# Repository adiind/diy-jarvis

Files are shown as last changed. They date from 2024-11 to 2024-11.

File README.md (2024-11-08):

# Voice-Controlled Smart Home Assistant 🎙️🏠
 




An intelligent IoT device built using the Maixduino Kit for AI + IoT, integrating voice recognition and motion detection to interact with Home Assistant via MQTT. The assistant recognizes specific voice commands, detects motion, and provides visual feedback through four white LEDs and two vertical RGB LED light bars. It updates the state of various entities in Home Assistant, enabling automation and enhancing user interaction with the smart home environment.

<div align="center">
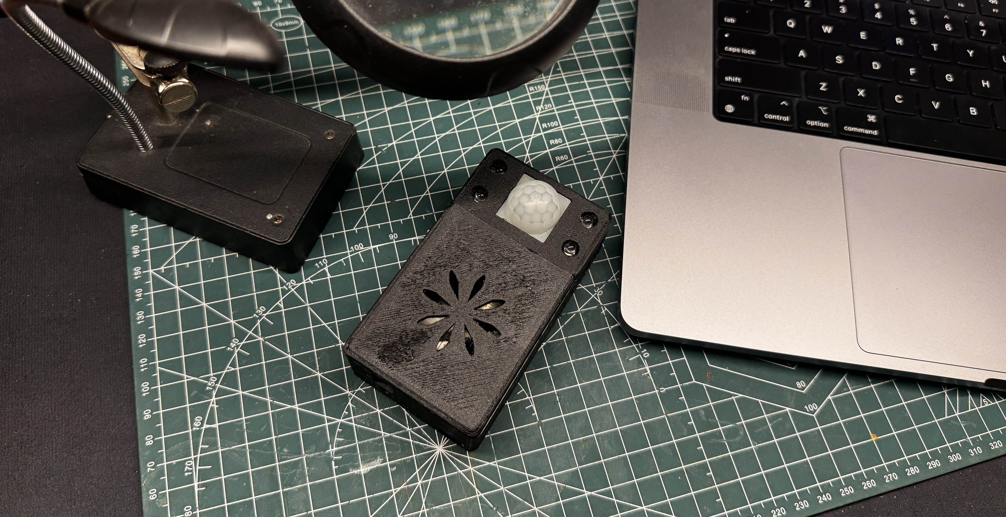
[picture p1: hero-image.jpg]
Smart Home Assistant Setup
  
</div>

## ✨ Key Features

- 🗣️ **Advanced Voice Recognition**: Custom-trained models with project-specific commands
- 📡 **Motion Detection**: PIR sensor technology for automated activation
- 💡 **Dynamic Visual Feedback**: 4 status LEDs + RGB light bars for clear system status
- 🏠 **Home Assistant Integration**: Comprehensive MQTT communication
- 🌙 **Smart Night Navigation**: Automatic lighting with motion detection
- ⚡ **Real-time State Management**: Instant updates and automation triggers
- 🛠️ **Easy Installation**: Non-destructive mounting and simple reset mechanism

## 📑 Table of Contents

- [Installation](#-installation)
- [Hardware Setup](#-hardware-setup)
- [Software Configuration](#-software-configuration)
- [Voice Model Generation](#-voice-model-generation)
- [Usage Guide](#-usage-guide)
- [Troubleshooting](#-troubleshooting)
- [Contributing](#-contributing)
- [License](#-license)

## 📦 Installation

### Hardware Requirements

Component | Purpose | Specifications
----------|----------|-------------
Maixduino Kit | Core Processing | AI + IoT version
ESP32 Module | Wi-Fi Communication | Built into Maixduino
PIR Sensor (HC-SR501) | Motion Detection | 3.3V compatible
Status LEDs | Visual Feedback | 4x white LEDs
Current Limiting Resistors | LED Protection | 4x 220Ω
RGB Light Bars | Dynamic Feedback | 2x 104 LED strips (1.5m)
ESP8266 | LED Control | WLED firmware
Power Supply | System Power | 12V DC barrel connector
Mounting Hardware | Installation | 3M Command Strips
Reset Wires | Easy Access | 2x insulated wires

### Hardware Assembly

1. **Power Connections**
   ```
   12V DC → Maixduino barrel jack
   GND → Common ground bus
   ```

2. **Sensor Wiring**
   ```
   PIR VCC → 3.3V
   PIR GND → GND
   PIR OUT → D8
   ```

3. **Status LEDs**
   ```
   System LED  → D5 + 220Ω → GND
   Speech LED  → D4 + 220Ω → GND
   Network LED → D3 + 220Ω → GND
   Motion LED  → D2 + 220Ω → GND
   ```

4. **Light Bars**
   - Mount vertically using Command Strips
   - Connect to ESP8266 running WLED
   - Power via 12V supply

5. **Reset Access**
   - Connect wire 1 to Reset pin
   - Connect wire 2 to GND pin
   - Route both wires through case opening
   - Insulate exposed ends
   - Label wires clearly

## 🎤 Voice Model Generation

### Prerequisites
- Maixduino Kit
- USB Cable
- CoolTerm Software
- Python 3.x Environment

### Voice Recording Environment Setup

1. **Physical Setup**
   - Install device in final location
   - Ensure case is fully assembled
   - Position at intended height
   - Verify proper ventilation

2. **Recording Environment**
   - Minimize background noise
   - Maintain consistent ~50cm distance
   - Use normal speaking voice
   - Test acoustics of space

### CoolTerm Configuration

1. **Initial Setup**
   ```
   Port: Select Maixduino COM port
   Baud Rate: 115200
   Data Bits: 8
   Stop Bits: 1
   Parity: None
   ```

2. **Buffer Settings**
   - Set buffer size to 75000
   - Enable "Capture to Text File"
   - Clear buffer between recordings

### Reset Procedure for Voice Model Recording

1. **Preparation**
   - Locate labeled reset and GND wires
   - Ensure clean wire ends
   - Have recording script ready

2. **Recording Process**
   - Touch reset and GND wires together briefly
   - Wait for LED confirmation of reboot
   - Begin recording when prompted
   - Maintain consistent voice level
   - Complete all 6 samples
   - Save file with descriptive name

3. **Safety Notes**
   - Keep wire ends separated when not in use
   - Consider adding small connectors
   - Avoid touching other components
   - Keep wires away from interference sources

### Project-Specific Voice Commands

Command ID | Phrase | Function | Description
-----------|--------|----------|-------------
1 | "Alfred Let's Go" | System Activation | Initializes main system functions
2 | "Bye Bye Jarvis" | System Shutdown | Graceful shutdown sequence
3 | "Cooking Mode" | Kitchen Control | Activates kitchen-specific settings
4 | "Goodnight Jarvis" | Night Mode | Evening shutdown routine
5 | "Jarvis Good Morning" | Morning Mode | Morning activation sequence
6 | "Jarvis Lights On" | Lighting Control | Activates configured lights
7 | "Lights Off Jarvis" | Lighting Control | Deactivates all lights
8 | "Wake Up Jarvis" | System Wake | Resumes from sleep mode
9 | "Clap Clap" | Attention Mode | Quick system attention
10 | "Jarvis Demo Mode" | Demonstration | Shows system capabilities

## 💻 Software Configuration

### MQTT Topics Structure
```cpp
// System State Topics
const char* motion_state_topic = "home-assistant/voice-control/motion/state";
const char* alfred_state_topic = "home-assistant/voice-control/alfred/state";
const char* system_state_topic = "home-assistant/voice-control/system/state";
const char* cooking_state_topic = "home-assistant/voice-control/cooking/state";
const char* goodnight_state_topic = "home-assistant/voice-control/goodnight/state";
const char* goodmorning_state_topic = "home-assistant/voice-control/goodmorning/state";
const char* light_state_topic = "home-assistant/voice-control/light/state";
```

### Home Assistant Configuration
```yaml
# MQTT Configuration
mqtt:
  binary_sensor:
    - name: "Voice Control Motion"
      state_topic: "home-assistant/voice-control/motion/state"
      device_class: "motion"
      unique_id: "voice-control-motion"

  switch:
    - name: "Alfred Mode"
      state_topic: "home-assistant/voice-control/alfred/state"
      unique_id: "voice-control-alfred"
      icon: "mdi:butler"
    
    - name: "Voice Control System"
      state_topic: "home-assistant/voice-control/system/state"
      unique_id: "voice-control-system"
      icon: "mdi:voice"
    
    - name: "Cooking Mode"
      state_topic: "home-assistant/voice-control/cooking/state"
      unique_id: "voice-control-cooking"
      icon: "mdi:stove"
    
    - name: "Goodnight Mode"
      state_topic: "home-assistant/voice-control/goodnight/state"
      unique_id: "voice-control-goodnight"
      icon: "mdi:weather-night"
    
    - name: "Good Morning Mode"
      state_topic: "home-assistant/voice-control/goodmorning/state"
      unique_id: "voice-control-goodmorning"
      icon: "mdi:weather-sunny"
    
    - name: "Voice Control Light"
      state_topic: "home-assistant/voice-control/light/state"
      unique_id: "voice-control-light"
      icon: "mdi:lightbulb"
```

## 🎯 Usage Guide

### Basic Operation
1. Power-up sequence initiates automatically
2. System LED indicates ready state
3. Motion detection activates voice recognition
4. Voice commands trigger corresponding actions
5. Light bars provide visual confirmation
6. Status LEDs show current system state

### Night Navigation
- Motion triggers soft lighting
- Auto-off after 4 seconds
- Adjustable sensitivity via Home Assistant
- Smooth fade transitions

## ❗ Troubleshooting

Issue | Check | Solution
------|-------|----------
No power | Power LED | Verify 12V supply
Voice recognition fails | Speech LED | Retrain voice models
Motion detection issues | Motion LED | Adjust PIR sensitivity
No MQTT connection | Network LED | Check Wi-Fi settings
Light bars unresponsive | WLED status | Verify ESP8266 connection
Reset not working | Reset wires | Check wire connections

## 📄 License

This project is licensed under the MIT License - see [LICENSE](LICENSE) file.

## 🙏 Acknowledgments

- [Circuit Digest](https://circuitdigest.com/) and [DigiKey](https://www.digikey.com/) for sponsoring the Maixduino board as part of the IoT & Edge AI Project Challenge (DESIGN CONTEST IoT & Edge AI Project Challenge with DIGIKEY)
- [Maixduino](https://github.com/sipeed/Maixduino) team for the excellent AI + IoT platform
- [Home Assistant](https://www.home-assistant.io/) community for the automation framework
- [WLED](https://github.com/Aircoookie/WLED) project for the LED control firmware

---

<div align="center">
  Made with ❤️ by Tinker Verse
  
  ⭐ Star this project
</div>

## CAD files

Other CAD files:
Enclsure f3d,stl 3D files/Jarvis Enclosure v5.f3d

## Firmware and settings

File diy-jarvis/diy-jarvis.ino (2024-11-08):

#include "WiFiEsp.h"
#include <PubSubClient.h>
#include "Maix_Speech_Recognition.h"
#include "voice_model.h"

#ifndef HAVE_HWSERIAL1
#include "SoftwareSerial.h"
SoftwareSerial Serial1(6, 7); // RX, TX
#endif

// WiFi and MQTT settings
const char* ssid = "Your WIFI";
const char* password = "***********";
const char* mqtt_server = "server ip";
const char* mqtt_username = "username";
const char* mqtt_password = "password";
const int mqtt_port = 1883;

// MQTT Topics
const char* motion_state_topic = "home-assistant/voice-control/motion/state";
const char* alfred_state_topic = "home-assistant/voice-control/alfred/state";
const char* system_state_topic = "home-assistant/voice-control/system/state";
const char* cooking_state_topic = "home-assistant/voice-control/cooking/state";
const char* goodnight_state_topic = "home-assistant/voice-control/goodnight/state";
const char* goodmorning_state_topic = "home-assistant/voice-control/goodmorning/state";
const char* light_state_topic = "home-assistant/voice-control/light/state";
const char* clap_state_topic = "home-assistant/voice-control/clap/state";
const char* demo_state_topic = "home-assistant/voice-control/demo/state";
// Initialize objects
WiFiEspClient espClient;
PubSubClient client(espClient);
SpeechRecognizer rec;

// State variables
int status = WL_IDLE_STATUS;
bool systemActive = false;
bool alfredState = false;
bool cookingState = false;
bool goodnightState = false;
bool goodmorningState = false;
bool lightState = false;
bool motionDetected = false;
bool isListening = false;
unsigned long lastPirValue = LOW;
unsigned long lastMotionTime = 0;
unsigned long lastSpeechToggle = 0;
const unsigned long MOTION_TIMEOUT = 6000;
const unsigned long SPEECH_BLINK_INTERVAL = 100;
bool clapMode = false;
bool demoMode = false;
// Pin definitions
#define LED_SYSTEM 5    // System ON/OFF status
#define LED_SPEECH 4    // Speech recognition activity
#define LED_NETWORK 3   // Network status
#define LED_MOTION 2    // Motion detection
#define PIR_PIN 8       // Motion sensor
// Add new LED pattern timing constants
const unsigned long LED_SEQUENCE_DELAY = 100;  // Basic delay for LED sequences
const unsigned long LISTENING_PATTERN_INTERVAL = 200;  // For sound recognition pattern
const unsigned long WIFI_BLINK_INTERVAL = 300;  // For WiFi connecting pattern
const unsigned long MQTT_BLINK_INTERVAL = 200;  // For MQTT connecting pattern


// New function for startup LED sequence
void startupLEDSequence() {
    // All LEDs off initially
    digitalWrite(LED_SYSTEM, LOW);
    digitalWrite(LED_SPEECH, LOW);
    digitalWrite(LED_NETWORK, LOW);
    digitalWrite(LED_MOTION, LOW);
    delay(500);
    
    // Sequential lighting up
    for(int i = 0; i < 3; i++) {
        // Forward sequence
        digitalWrite(LED_SYSTEM, HIGH);
        delay(LED_SEQUENCE_DELAY);
        digitalWrite(LED_SPEECH, HIGH);
        delay(LED_SEQUENCE_DELAY);
        digitalWrite(LED_NETWORK, HIGH);
        delay(LED_SEQUENCE_DELAY);
        digitalWrite(LED_MOTION, HIGH);
        delay(LED_SEQUENCE_DELAY);
        
        // Reverse sequence
        digitalWrite(LED_MOTION, LOW);
        delay(LED_SEQUENCE_DELAY);
        digitalWrite(LED_NETWORK, LOW);
        delay(LED_SEQUENCE_DELAY);
        digitalWrite(LED_SPEECH, LOW);
        delay(LED_SEQUENCE_DELAY);
        digitalWrite(LED_SYSTEM, LOW);
        delay(LED_SEQUENCE_DELAY * 2);
    }
    
    // Final flash all together
    for(int i = 0; i < 3; i++) {
        digitalWrite(LED_SYSTEM, HIGH);
        digitalWrite(LED_SPEECH, HIGH);
        digitalWrite(LED_NETWORK, HIGH);
        digitalWrite(LED_MOTION, HIGH);
        delay(LED_SEQUENCE_DELAY * 2);
        digitalWrite(LED_SYSTEM, LOW);
        digitalWrite(LED_SPEECH, LOW);
        digitalWrite(LED_NETWORK, LOW);
        digitalWrite(LED_MOTION, LOW);
        delay(LED_SEQUENCE_DELAY * 2);
    }
}

// New function for WiFi connecting sequence
void wifiConnectingSequence() {
    static unsigned long lastWifiToggle = 0;
    static int ledState = 0;
    
    if (millis() - lastWifiToggle >= WIFI_BLINK_INTERVAL) {
        lastWifiToggle = millis();
        
        // Reset all LEDs
        digitalWrite(LED_SYSTEM, LOW);
        digitalWrite(LED_SPEECH, LOW);
        digitalWrite(LED_NETWORK, LOW);
        digitalWrite(LED_MOTION, LOW);
        
        // Light up current LED
        switch(ledState) {
            case 0: digitalWrite(LED_SYSTEM, HIGH); break;
            case 1: digitalWrite(LED_SPEECH, HIGH); break;
            case 2: digitalWrite(LED_NETWORK, HIGH); break;
            case 3: digitalWrite(LED_MOTION, HIGH); break;
        }
        
        ledState = (ledState + 1) % 4;
    }
}

void publishState(const char* topic, bool state) {
    client.publish(topic, state ? "ON" : "OFF", true);
}

void publishDiscoveryConfig() {
    // Motion Sensor Discovery Config
    String motionConfigTopic = String("homeassistant/binary_sensor/voice-control-motion/config");
    String motionConfig = "{"
        "\"name\": \"Voice Control Motion\","
        "\"state_topic\": \"" + String(motion_state_topic) + "\","
        "\"device_class\": \"motion\","
        "\"unique_id\": \"voice-control-motion\""
    "}";

    // Alfred Mode Discovery Config
    String alfredConfigTopic = String("homeassistant/switch/voice-control-alfred/config");
    String alfredConfig = "{"
        "\"name\": \"Alfred Mode\","
        "\"state_topic\": \"" + String(alfred_state_topic) + "\","
        "\"unique_id\": \"voice-control-alfred\""
    "}";

    // System State Discovery Config
    String systemConfigTopic = String("homeassistant/switch/voice-control-system/config");
    String systemConfig = "{"
        "\"name\": \"Voice Control System\","
        "\"state_topic\": \"" + String(system_state_topic) + "\","
        "\"unique_id\": \"voice-control-system\""
    "}";

    // Cooking Mode Discovery Config
    String cookingConfigTopic = String("homeassistant/switch/voice-control-cooking/config");
    String cookingConfig = "{"
        "\"name\": \"Cooking Mode\","
        "\"state_topic\": \"" + String(cooking_state_topic) + "\","
        "\"unique_id\": \"voice-control-cooking\""
    "}";

    // Goodnight Mode Discovery Config
    String goodnightConfigTopic = String("homeassistant/switch/voice-control-goodnight/config");
    String goodnightConfig = "{"
        "\"name\": \"Goodnight Mode\","
        "\"state_topic\": \"" + String(goodnight_state_topic) + "\","
        "\"unique_id\": \"voice-control-goodnight\""
    "}";

    // Good Morning Mode Discovery Config
    String goodmorningConfigTopic = String("homeassistant/switch/voice-control-goodmorning/config");
    String goodmorningConfig = "{"
        "\"name\": \"Good Morning Mode\","
        "\"state_topic\": \"" + String(goodmorning_state_topic) + "\","
        "\"unique_id\": \"voice-control-goodmorning\""
    "}";

    // Light Control Discovery Config
    String lightConfigTopic = String("homeassistant/switch/voice-control-light/config");
    String lightConfig = "{"
        "\"name\": \"Voice Control Light\","
        "\"state_topic\": \"" + String(light_state_topic) + "\","
        "\"unique_id\": \"voice-control-light\""
    "}";

    // Publish all configs
    client.publish(motionConfigTopic.c_str(), motionConfig.c_str(), true);
    client.publish(alfredConfigTopic.c_str(), alfredConfig.c_str(), true);
    client.publish(systemConfigTopic.c_str(), systemConfig.c_str(), true);
    client.publish(cookingConfigTopic.c_str(), cookingConfig.c_str(), true);
    client.publish(goodnightConfigTopic.c_str(), goodnightConfig.c_str(), true);
    client.publish(goodmorningConfigTopic.c_str(), goodmorningConfig.c_str(), true);
    client.publish(lightConfigTopic.c_str(), lightConfig.c_str(), true);
}

bool reconnect() {
    Serial.print("Attempting MQTT connection... ");
    String clientId = "VoiceControlClient-";
    clientId += String(random(0xffff), HEX);
    
    if (client.connect(clientId.c_str(), mqtt_username, mqtt_password)) {
        Serial.println("connected");
        publishDiscoveryConfig();
        // Publish initial states
        publishState(motion_state_topic, false);
        publishState(alfred_state_topic, alfredState);
        publishState(system_state_topic, systemActive);
        publishState(cooking_state_topic, cookingState);
        publishState(goodnight_state_topic, goodnightState);
        publishState(goodmorning_state_topic, goodmorningState);
        publishState(light_state_topic, lightState);
        return true;
    }
    Serial.print("failed, rc=");
    Serial.print(client.state());
    Serial.println(" retry in 5s");
    return false;
}


// Updated setup_wifi function
void setup_wifi() {
    if (WiFi.status() == WL_NO_SHIELD) {
        Serial.println("WiFi shield not present");
        while (true) {
            // Error pattern - all LEDs flash together
            digitalWrite(LED_SYSTEM, HIGH);
            digitalWrite(LED_SPEECH, HIGH);
            digitalWrite(LED_NETWORK, HIGH);
            digitalWrite(LED_MOTION, HIGH);
            delay(500);
            digitalWrite(LED_SYSTEM, LOW);
            digitalWrite(LED_SPEECH, LOW);
            digitalWrite(LED_NETWORK, LOW);
            digitalWrite(LED_MOTION, LOW);
            delay(500);
        }
    }

    Serial.print("Attempting to connect to WPA SSID: ");
    Serial.println(ssid);
    
    while (status != WL_CONNECTED) {
        status = WiFi.begin(ssid, password);
        wifiConnectingSequence();
        delay(100);
    }

    // Success pattern - sequential light up and stay on
    digitalWrite(LED_SYSTEM, HIGH);
    delay(200);
    digitalWrite(LED_SPEECH, HIGH);
    delay(200);
    digitalWrite(LED_NETWORK, HIGH);
    delay(200);
    digitalWrite(LED_MOTION, HIGH);
    delay(1000);
    
    Serial.println("\nConnected to the network");
    Serial.print("IP Address: ");
    Serial.println(WiFi.localIP());
}


void checkMotion() {
    int currentPirValue = digitalRead(PIR_PIN);
    unsigned long currentTime = millis();
    
    if (currentPirValue == HIGH && lastPirValue == LOW) {
        motionDetected = true;
        lastMotionTime = currentTime;
        publishState(motion_state_topic, true);
        digitalWrite(LED_MOTION, HIGH);
        Serial.println("------ MOTION DETECTION ------");
        Serial.println("Status: Motion DETECTED!");
        Serial.println("Time: " + String(currentTime));
        Serial.println("----------------------------");
    }
    
    if (motionDetected && (currentTime - lastMotionTime >= MOTION_TIMEOUT)) {
        motionDetected = false;
        publishState(motion_state_topic, false);
        digitalWrite(LED_MOTION, LOW);
        Serial.println("------ MOTION TIMEOUT ------");
        Serial.println("Status: Motion ENDED");
        Serial.println("Duration: " + String((currentTime - lastMotionTime)) + "ms");
        Serial.println("--------------------------");
    }
    
    lastPirValue = currentPirValue;
}

void updateSpeechLED() {
    static unsigned long lastPattern = 0;
    static int patternState = 0;
    
    if (isListening) {
        if (millis() - lastPattern >= LISTENING_PATTERN_INTERVAL) {
            lastPattern = millis();
            
            // All LEDs on during listening mode
            digitalWrite(LED_SYSTEM, HIGH);
            digitalWrite(LED_SPEECH, HIGH);
            digitalWrite(LED_NETWORK, HIGH);
            digitalWrite(LED_MOTION, HIGH);
        }
    } else {
        // Return to normal LED states
        digitalWrite(LED_SYSTEM, systemActive);
        digitalWrite(LED_SPEECH, LOW);
        digitalWrite(LED_NETWORK, client.connected());
        digitalWrite(LED_MOTION, motionDetected);
    }
}


// Updated handleVoiceCommand function to include new commands
void handleVoiceCommand(int result) {
    isListening = false;
    
    // Command acknowledgment flash pattern
    for(int i = 0; i < 2; i++) {
        digitalWrite(LED_SPEECH, HIGH);
        delay(100);
        digitalWrite(LED_SPEECH, LOW);
        delay(100);
    }
    
    Serial.println("------ VOICE COMMAND DETECTED ------");
    Serial.print("Command ID: ");
    Serial.println(result);
    
    switch(result) {
        case 1:  // alfred_batcave_on
            alfredState = !alfredState;
            publishState(alfred_state_topic, alfredState);
            Serial.println("Command: Alfred Batcave On");
            Serial.println("Action: Toggle Alfred Mode");
            Serial.println("New State: " + String(alfredState ? "ON" : "OFF"));
            break;
            
        case 2:  // bye_bye_jarvis_jarvis
            systemActive = false;
            publishState(system_state_topic, false);
            digitalWrite(LED_SYSTEM, LOW);
            Serial.println("Command: Bye Bye Jarvis");
            Serial.println("Action: System Deactivated");
            break;
            
        case 3:  // cooking_mode
            cookingState = !cookingState;
            publishState(cooking_state_topic, cookingState);
            Serial.println("Command: Cooking Mode");
            Serial.println("Action: Toggle Cooking Mode");
            Serial.println("New State: " + String(cookingState ? "ON" : "OFF"));
            break;
            
        case 4:  // goodnight_jarvis
            goodnightState = !goodnightState;
            publishState(goodnight_state_topic, goodnightState);
            Serial.println("Command: Goodnight Jarvis");
            Serial.println("Action: Toggle Goodnight Mode");
            Serial.println("New State: " + String(goodnightState ? "ON" : "OFF"));
            break;
            
        case 5:  // jarvis_goodmorning
            goodmorningState = !goodmorningState;
            publishState(goodmorning_state_topic, goodmorningState);
            Serial.println("Command: Jarvis Good Morning");
            Serial.println("Action: Toggle Good Morning Mode");
            Serial.println("New State: " + String(goodmorningState ? "ON" : "OFF"));
            break;
            
        case 6:  // jarvis_lights_on
            lightState = true;
            publishState(light_state_topic, true);
            Serial.println("Command: Jarvis Lights On");
            Serial.println("Action: Lights ON");
            break;
            
        case 7:  // lights_off_jarvis
            lightState = false;
            publishState(light_state_topic, false);
            Serial.println("Command: Lights Off Jarvis");
            Serial.println("Action: Lights OFF");
            break;
            
        case 8:  // wake_up_jarvis
            systemActive = true;
            publishState(system_state_topic, true);
            digitalWrite(LED_SYSTEM, HIGH);
            Serial.println("Command: Wake Up Jarvis");
            Serial.println("Action: System Activated");
            break;

        case 9:  // clap_clap
            clapMode = !clapMode;
            publishState(clap_state_topic, clapMode);
            Serial.println("Command: Clap Clap");
            Serial.println("Action: Toggle Clap Mode");
            Serial.println("New State: " + String(clapMode ? "ON" : "OFF"));
            break;
            
        case 10:  // jarvis_demo_mode
            demoMode = !demoMode;
            publishState(demo_state_topic, demoMode);
            Serial.println("Command: Jarvis Demo Mode");
            Serial.println("Action: Toggle Demo Mode");
            Serial.println("New State: " + String(demoMode ? "ON" : "OFF"));
            break;
    }
    Serial.println("--------------------------------");
}
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
void loop() {
    static unsigned long lastReconnectAttempt = 0;
    
    // Update network LED
    digitalWrite(LED_NETWORK, client.connected() ? HIGH : LOW);
    
    // Handle MQTT connection
    if (!client.connected()) {
        unsigned long now = millis();
        if (now - lastReconnectAttempt > 5000) {
            lastReconnectAttempt = now;
            if (reconnect()) {
                lastReconnectAttempt = 0;
            }
        }
    } else {
        client.loop();
    }
    
    // Check motion
    checkMotion();
    
    // Process voice commands if system is active or motion detected
    if (motionDetected || systemActive) {
        isListening = true;
        updateSpeechLED();
        int result = rec.recognize();
        if (result > 0) {
            handleVoiceCommand(result);
        }
    } else {
        isListening = false;
        updateSpeechLED();
    }
} 

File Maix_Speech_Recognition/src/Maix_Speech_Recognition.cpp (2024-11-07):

#include "Maix_Speech_Recognition.h"
#include <stdint.h>
#include <stdlib.h>
#include <stdio.h>
#include <string.h>
#include "sysctl.h"
#include "plic.h"
#include "uarths.h"
#include "util/g_def.h"
#include "i2s.h"
#include "fpioa.h"

#include "util/VAD.h"
#include "util/MFCC.h"
#include "util/DTW.h"
#include "util/flash.h"
#include "util/ADC.h"

#define USART1_printf Serial.printf

uint16_t VcBuf[atap_len];
atap_tag    atap_arg;
valid_tag   valid_voice[max_vc_con];
v_ftr_tag   ftr;
v_ftr_tag   ftr_temp;
v_ftr_tag   ftr_mdl_temp[10];
v_ftr_tag   *pftr_mdl_temp[10];

#define save_ok     0
#define VAD_fail    1
#define MFCC_fail   2
#define Flash_fail  3

#define FFT_N 512

uint16_t rx_buf[FRAME_LEN];
uint32_t g_rx_dma_buf[FRAME_LEN * 2];
uint64_t fft_out_data[FFT_N / 2];

volatile uint32_t g_index;
volatile uint8_t uart_rec_flag;
volatile uint32_t receive_char;
volatile uint8_t i2s_rec_flag;
volatile uint8_t i2s_start_flag = 0;

int i2s_dma_irq(void *ctx)
{
    uint32_t i;
    if(i2s_start_flag)
    {
        int16_t s_tmp;
        if(g_index)
        {
            i2s_receive_data_dma(I2S_DEVICE_0, &g_rx_dma_buf[g_index], frame_mov * 2, DMAC_CHANNEL3);
            g_index = 0;
            for(i = 0; i < frame_mov; i++)
            {
                s_tmp = (int16_t)(g_rx_dma_buf[2 * i] & 0xffff); //g_rx_dma_buf[2 * i + 1] Low left
                rx_buf[i] = s_tmp + 32768;
            }
            i2s_rec_flag = 1;
        }
        else
        {
            i2s_receive_data_dma(I2S_DEVICE_0, &g_rx_dma_buf[0], frame_mov * 2, DMAC_CHANNEL3);
            g_index = frame_mov * 2;
            for(i = frame_mov; i < frame_mov * 2; i++)
            {
                s_tmp = (int16_t)(g_rx_dma_buf[2 * i] & 0xffff);//g_rx_dma_buf[2 * i + 1] Low left
                rx_buf[i] = s_tmp + 32768;
            }
            i2s_rec_flag = 2;
        }
    }
    else
    {
        i2s_receive_data_dma(I2S_DEVICE_0, &g_rx_dma_buf[0], frame_mov * 2, DMAC_CHANNEL3);
        g_index = frame_mov * 2;
    }
    return 0;
}

SpeechRecognizer::SpeechRecognizer() {
    // Initialize tracking arrays
    memset(models_per_command, 0, MAX_KEYWORDS);
    memset(is_model_valid, 0, MAX_KEYWORDS * MAX_MODELS_PER_KEY);
}
SpeechRecognizer::~SpeechRecognizer(){
    
}

int
SpeechRecognizer::begin()
{
    //io_mux_init
    fpioa_set_function(20, FUNC_I2S0_IN_D0);
    fpioa_set_function(18, FUNC_I2S0_SCLK);
    fpioa_set_function(19, FUNC_I2S0_WS);

    //i2s init
    i2s_init(I2S_DEVICE_0, I2S_RECEIVER, 0x3);

    i2s_rx_channel_config(I2S_DEVICE_0, I2S_CHANNEL_0,
            RESOLUTION_16_BIT, SCLK_CYCLES_32,
            TRIGGER_LEVEL_4, STANDARD_MODE);

    i2s_set_sample_rate(I2S_DEVICE_0, 8000);

    dmac_init();
    dmac_set_irq(DMAC_CHANNEL3, i2s_dma_irq, NULL, 3);
    i2s_receive_data_dma(I2S_DEVICE_0, &g_rx_dma_buf[0], frame_mov * 2, DMAC_CHANNEL3);

    /* Enable the machine interrupt */
    sysctl_enable_irq();
    return 0;
}

int
SpeechRecognizer::record(uint8_t keyword_num, uint8_t model_num)
{
    if (keyword_num > 10) return -1;
    if (model_num > 4)    return -2;
    
    comm = keyword_num;
    uint8_t prc_count = model_num;
    uint32_t addr = 0;

    g_index = 0;
    i2s_rec_flag = 0;
    i2s_start_flag = 1;
    
    addr = ftr_start_addr + comm * size_per_comm + prc_count * size_per_ftr;

    if (save_mdl(VcBuf, addr) == save_ok) {
        return 0;
    }else{
        return -3;
    }

}

int
SpeechRecognizer::recognize()
{
    u8 res;
    u32 dis;

    g_index = 0;
    i2s_rec_flag = 0;
    i2s_start_flag = 1;

    res = spch_recg(VcBuf, &dis);
    if(dis != dis_err) 
        return res;
    else
        return -1;
}
int SpeechRecognizer::addVoiceModel(uint8_t keyword_num, uint8_t model_num, const int16_t *voice_model, uint16_t frame_num) {
    if(keyword_num >= MAX_KEYWORDS || model_num >= MAX_MODELS_PER_KEY)
        return -1;
        
    ftr_save[keyword_num * MAX_MODELS_PER_KEY + model_num].save_sign = save_mask;
    ftr_save[keyword_num * MAX_MODELS_PER_KEY + model_num].frm_num = frame_num;

    for (int i = 0; i < (vv_frm_max * mfcc_num); i++)
        ftr_save[keyword_num * MAX_MODELS_PER_KEY + model_num].mfcc_dat[i] = voice_model[i];
        
    // Update tracking
    is_model_valid[keyword_num][model_num] = true;
    if(model_num >= models_per_command[keyword_num])
        models_per_command[keyword_num] = model_num + 1;
        
    return 0;
}
int
SpeechRecognizer::print_model(uint8_t keyword_num, uint8_t model_num)
{
    Serial.printf("frm_num=%d\n", ftr_save[keyword_num*4 + model_num].frm_num);
    for (int i = 0; i < (vv_frm_max * mfcc_num); i++) {
        if (((i + 1) % 35) == 0)
            Serial.printf("%d,\n", ftr_save[keyword_num*4 + model_num].mfcc_dat[i]);
        else
            Serial.printf("%d, ", ftr_save[keyword_num*4 + model_num].mfcc_dat[i]);
    }
    Serial.printf("\nprint model ok!\n");
    return 0;
}

uint8_t SpeechRecognizer::save_mdl(uint16_t *v_dat, uint32_t addr)
{
    u16 i, num;
    u16 frame_index;
get_noise1:
    frame_index = 0;
    num = atap_len / frame_mov;
    //wait for finish
    while (1) {
        while (i2s_rec_flag == 0)
            continue;
        if (i2s_rec_flag == 1) {
            for (i = 0; i < frame_mov; i++)
                v_dat[frame_mov * frame_index + i] = rx_buf[i];
        } else {
            for (i = 0; i < frame_mov; i++)
                v_dat[frame_mov * frame_index + i] = rx_buf[i + frame_mov];
        }
        i2s_rec_flag = 0;
        frame_index++;
        if (frame_index >= num)
            break;
    }
//  for(i = 0; i < atap_len; i++)
//      Serial.printf("noise: %d\n", v_dat[i]);
    noise_atap(v_dat, atap_len, &atap_arg);
    if (atap_arg.s_thl > 10000) {
        Serial.printf("get noise again...\n");
        goto get_noise1;
    }
    Serial.printf("speeking...\n");
//wait for finish
    while (i2s_rec_flag == 0)
        continue;
    if (i2s_rec_flag == 1) {
        for (i = 0; i < frame_mov; i++)
            v_dat[i + frame_mov] = rx_buf[i];
    } else {
        for (i = 0; i < frame_mov; i++)
            v_dat[i + frame_mov] = rx_buf[i + frame_mov];
    }
    i2s_rec_flag = 0;
    while (1) {
        while (i2s_rec_flag == 0)
            continue;
        if (i2s_rec_flag == 1) {
            for (i = 0; i < frame_mov; i++) {
                v_dat[i] = v_dat[i + frame_mov];
                v_dat[i + frame_mov] = rx_buf[i];
            }
        } else {
            for (i = 0; i < frame_mov; i++) {
                v_dat[i] = v_dat[i + frame_mov];
                v_dat[i + frame_mov] = rx_buf[i + frame_mov];
            }
        }
        i2s_rec_flag = 0;
        if (VAD2(v_dat, valid_voice, &atap_arg) == 1)
            break;
        if (receive_char == 's')
            return MFCC_fail;
    }
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

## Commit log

2024-11-07 Fixed voice model calls and timout
    [diy-jarvis.ino]
2024-11-08 Added f3d files
    [Jarvis Enclosure v5.f3d]

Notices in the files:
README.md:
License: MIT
